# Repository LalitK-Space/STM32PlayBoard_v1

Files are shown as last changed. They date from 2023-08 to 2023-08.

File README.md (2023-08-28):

# STM32PlayBoard_v1

## Project Overview
<p>An STM32-based development board for boundless exploration in Embedded Systems. </p> 
Introducing the STM32PlayBoard. As the name suggests, the main object of developing this board is to expand my knowledge and provide an entry gate for others to learn Embedded Systems with a well-known and documented microcontroller by STMicroelectronics. 
<p>This project opens the door to immersive learning experiences and practical experimentation.

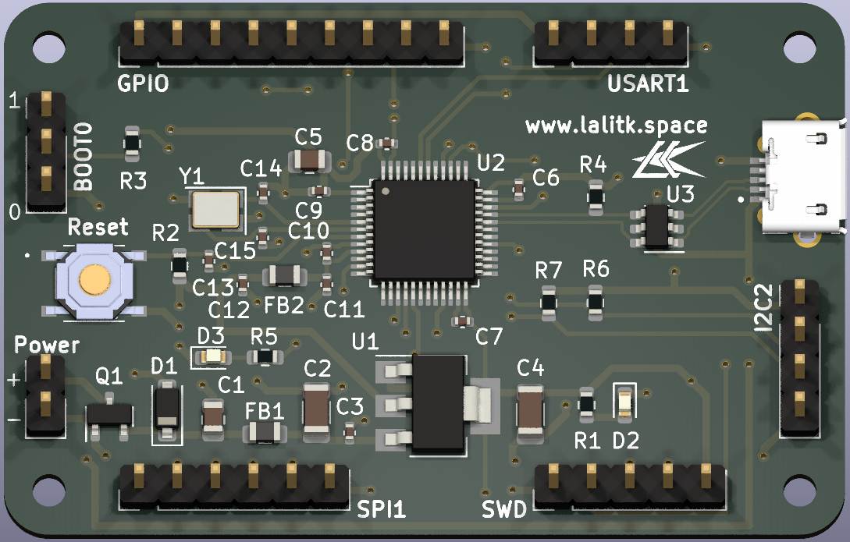
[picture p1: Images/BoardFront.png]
Top
 
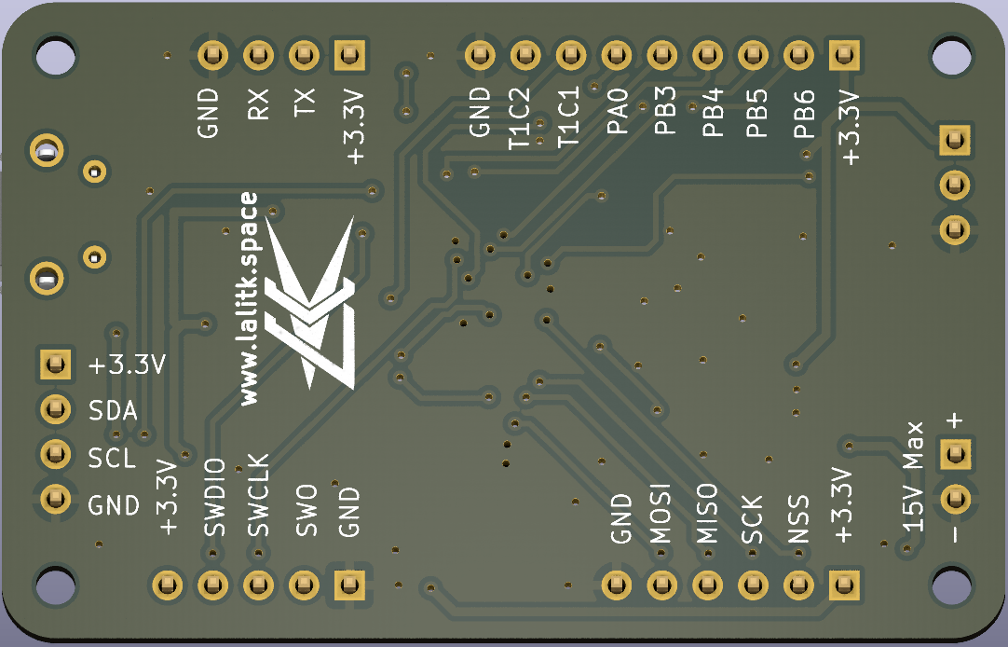
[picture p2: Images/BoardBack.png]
Bottom


## Why I Designed the STM32PlayBoard?
A Catalyst for Growth and Innovation, the reason for the development of STM32PlayBoard was rooted in a dual ambition: to push the boundaries of my expertise in PCB design while creating a versatile tool that resonates with my journey in Embedded Systems.
1.	**Elevating PCB Design Expertise:** This project moved me into a relatively complex PCB design I was familiar with. It also provided a stage to experiment with diverse PCB manufacturing and assembly services, broadening my understanding of the complexities of hardware production.
2.	**Fulfilling a Learning Trip:** While learning about ARM Cortex-M architectures, I have always used a variety of STMicroelectronics boards. Recently, I wanted to develop a basic yet peripheral-rich custom board.

## Design Philosophy
<p>I pictured a compact design for the STM32PlayBoard that prioritized accessibility to a wide range of communication protocols while offering dedicated pins for ADC, timers, and some general-purpose I/Os. 
<p>This careful pin allocation aimed to balance versatility, functionality, and ease in PCB designing. By providing exposure to commonly used communication interfaces and essential GPIO options, the board becomes an adaptable platform for various applications.
<p>Additionally, the compact nature of the design wasn't just about efficient use of space; it also served a practical purpose. I aimed to create a development board that could seamlessly integrate into my other projects as a convenient replacement. This design approach allows for easy adaptability across different projects, simplifying development and minimizing the need for significant redesigns.

## System Architecture
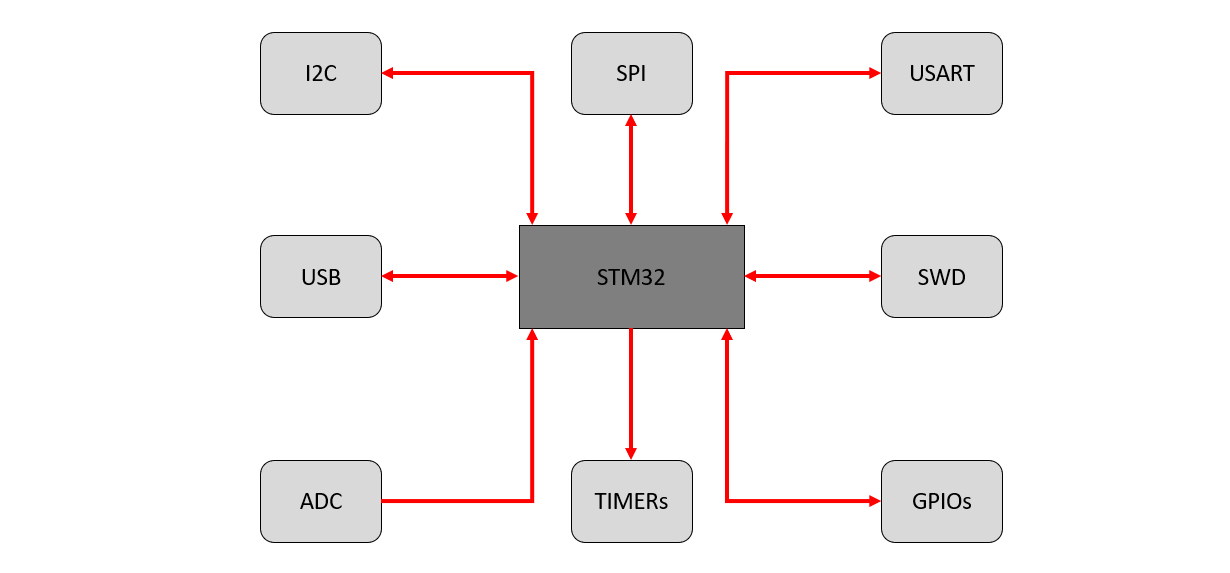
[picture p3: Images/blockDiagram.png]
Block Diagram/Architecture


## Board Component Selection
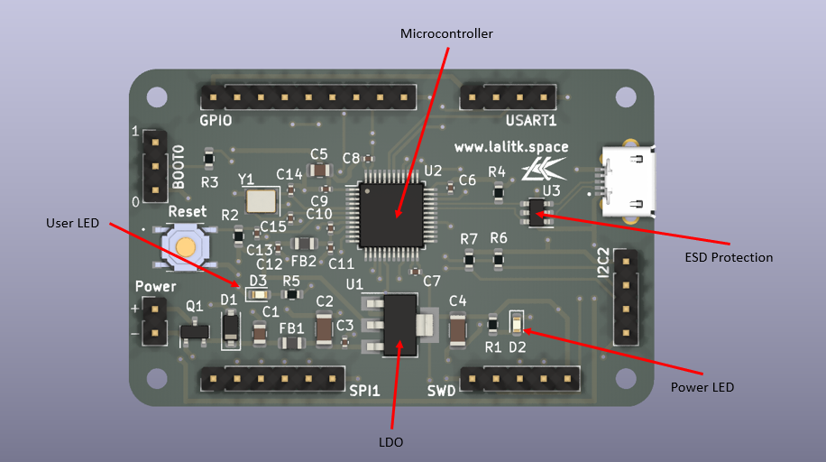
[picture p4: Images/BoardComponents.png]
Board Components

### Microcontroller:
1.	The board's core is an STM32F103C8T6 microcontroller from STMicroelectronics, running with a 16MHz High-Speed External Oscillator.
2.	Board has a configurable BOOT0 for different operational modes.
3.	A physical reset button for manually resetting the board.
### Power Supply:
1.	The board can be powered by an external voltage supply and through Micro B USB. They are reverse polarity protected and can both coexist.
2.	The voltage regulation is accomplished using AMS1117-3.3 linear voltage regulator from Advanced Monolithic Systems. Since the main component on the board is the main microcontroller IC, I went with this standard, less expensive, and easily available LDO.
3.	The maximum voltage that can be provided externally is 18V, and the maximum drop-out voltage of this LDO is 1.2V at 1A. We are going to be far from this current consumption using this board.
4. The Silkscreen on the back side of the PCB shows 15V is just an additional safety measure (not to exceed 15V even though up to 18V is acceptable).
### USB:
1.	The board supports USB 2.0 full-speed interface using a Micro B connector.
2.	The board provides ESD protection on USB using USBLC6 IC from STMicroelectronics.
### Onboard LEDs:
1.	D3 is onboard status LED and is connected to pin PA1. The cathode of the LED is permanent ground.
2.	D2 is the Power LED indicating a healthy power supply.

## PCB Design and Schematics:
### Schematics
[Schematics](https://github.com/LalitK-Space/STM32PlayBoard_v1/blob/main/STM32PlayBoard_Schematics/STM32PlayBoard_v1.pdf)

### Board Layout Considerations
1.	The PCB is two layered board. The reason for being two layers is I wanted to go with a simple board design, which also minimizes the production cost.
2.	The entire bottom layer of the board is grounded, and the Top layer is the signals layer.
3.	A wide trace of 0.5mm is for power, and a 0.3mm trace is for signals.
4. The board dimensions are 56x36mm. 
#### Front Copper
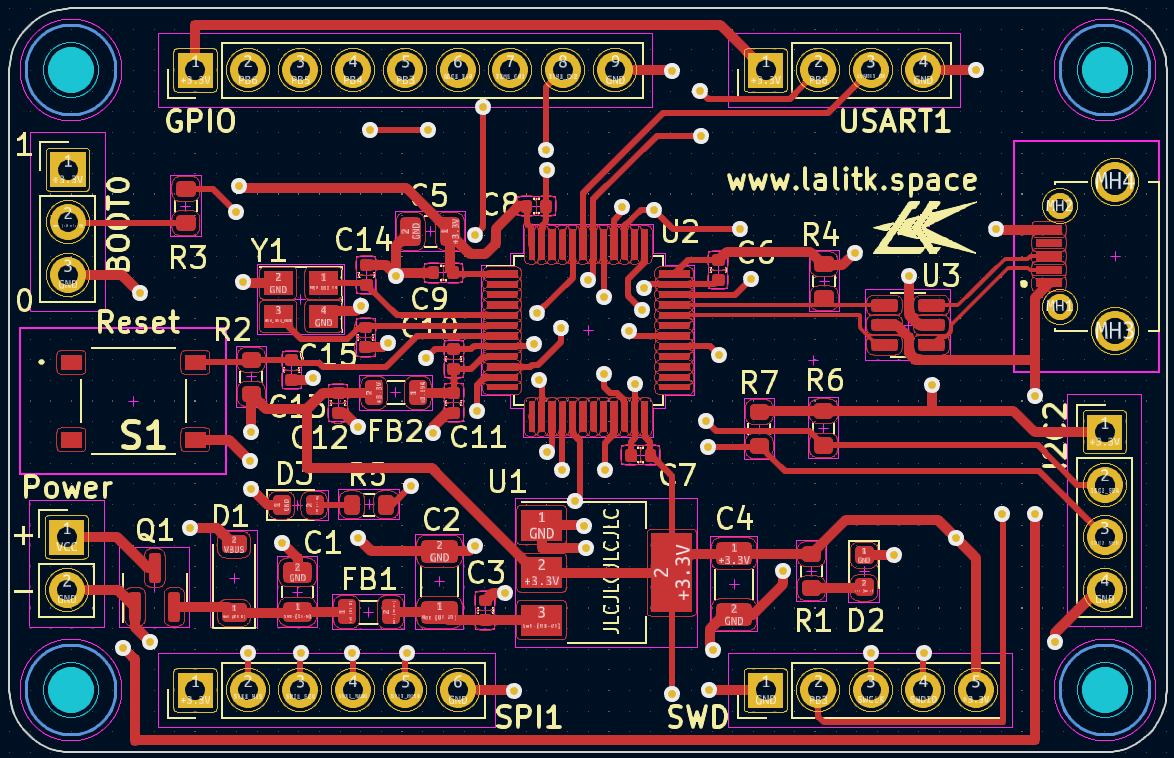
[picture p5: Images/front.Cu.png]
Front Copper

#### Back Copper
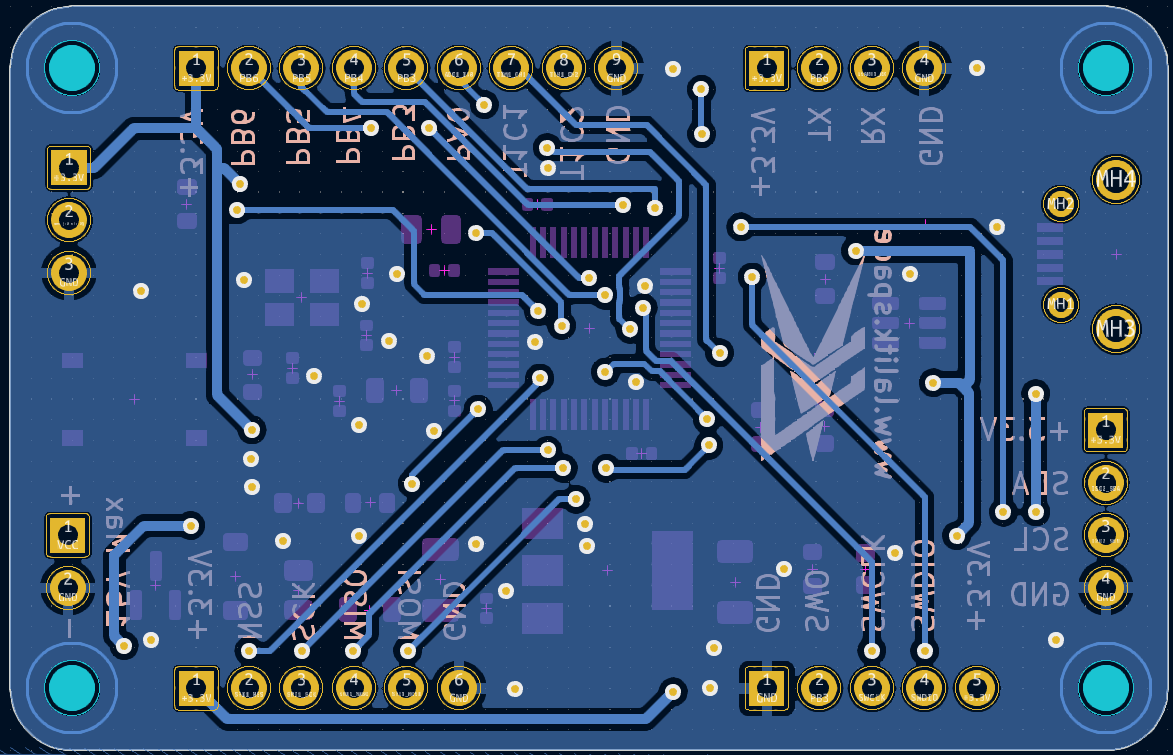
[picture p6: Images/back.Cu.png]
Back Copper


## Interfacing and Capabilities
1.	This board functions as a development board with GPIO and communication protocols exposed. 
The board exposes:
    <ul>
        <li>1 SPI connection (SPI1)</li>
        <li>1 I2C connection (I2C2)</li>
        <li>1 USART connection (USART1)</li>
        <li>SWD for programming and debugging</li>
        <li>1 ADC (ADC1_IN0)</li>
        <li>2 timers (TIM1_CH1 and TIM1_CH2)</li>
        <li>4 GPIOs from Port B (PB3, PB4, PB5, PB6)</li>
        <li>An onboard LED on pin PA1</li>
    </ul>
2. The voltage level for all the pins is 3.3V. And for interfacing with other 5V level compatible boards (for example, Arduino), a logic level shifter/converter is required.

## Software Development
The board can be programmed using an external ST-Link programmer via the SWD interface.

## Technical Specification
| Input Voltages | Max Values |
|---|:---:|
| Through USB connector | 5V | 
| Through Power connector | 18V |

| GPIO Tolerances | Max Values |
|---|:---:|
| All pins | 3.3V | 

| Memories | Size |
|---|:---:|
| FLASH | 64 Kbytes | 
| SRAM | 20 Kbytes | 

| Exposed Peripherals | Connected to |
|---|:---:|
| I2C2_SDA | PB11 | 
| I2C2_SCL | PB10 | 
| USART1_RX | PB7 |
| USART1_TX | PB6 |
| SPI1_NSS | PA4 |
| SPI1_SCK | PA5 |
| SPI1_MISO | PA6 |
| SPI1_MOSI | PA7 |
| Status LED D3 | PA1 |
| ADC1_IN0 | PA0 |
| TIM1_CH1 | PA8 |
| TIM1_CH2 | PA9 |
| GPIO1 (*USART1_TX*) | PB6 |
| GPIO2 | PB5 |
| GPIO3 | PB4 |
| GPIO4 (*SWO*) | PB3 |

## Board Bring-Up
### Manufactured and Assembled Board
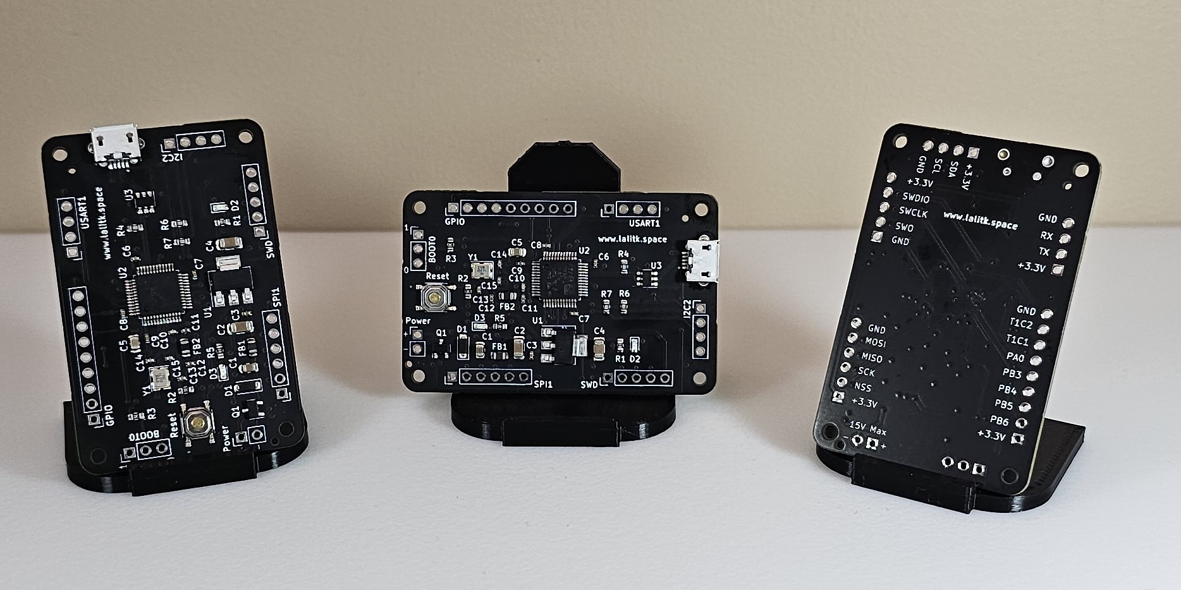
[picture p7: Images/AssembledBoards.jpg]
Assembled Boards

### Powering Up and Blinking Onboard LED
It's Alive

## My learnings
<p>Throughout the development of this board, I discovered a lot regarding designing a PCB with a microcontroller on it and various design practices like decoupling and bulk capacitors. I also wanted to learn to program a STMicroelectronics microcontroller using an external programmer, and I achieved this using this board.
<p>As per software development skills, I am writing my drivers for various peripherals and example codes for this board, which are available on this GitHub repository. 

## Foundations for the Future
<p>Keeping this project as a base, I would like to design and develop another STM32-based development board with a different, more powerful microcontroller with various onboard peripherals like FLASH memory and some onboard sensors communicating with the main IC using multiple communication protocols.

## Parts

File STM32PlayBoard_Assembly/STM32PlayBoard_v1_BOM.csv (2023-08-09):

Comment | Designator | Footprint | LCSC
10u | C1, C5 | Capacitor_SMD:C_0805_2012Metric | C15850
22u | C2, C4 | Capacitor_SMD:C_1206_3216Metric | C12891
100n | C3, C6, C7, C8, C9, C13 | Capacitor_SMD:C_0402_1005Metric | C1525
10n | C10 | Capacitor_SMD:C_0402_1005Metric | C15195
1u | C11, C12 | Capacitor_SMD:C_0402_1005Metric | C52923
10p | C14, C15 | Capacitor_SMD:C_0402_1005Metric | C32949
1N5819WS | D1 | Diode_SMD:D_SOD-123 | C8598
Power_LED | D2 | LED_SMD:LED_0603_1608Metric | C2286
Status_LED | D3 | LED_SMD:LED_0603_1608Metric | C2286
600Î©@100MHz | FB1, FB2 | Inductor_SMD:L_0805_2012Metric | C1017
MountingHole | H1, H2, H3, H4 | MountingHole:MountingHole_2.2mm_M2
PowerIN | J1 | Connector_PinHeader_2.54mm:PinHeader_1x02_P2.54mm_Vertical
BOOT0 | J2 | Connector_PinHeader_2.54mm:PinHeader_1x03_P2.54mm_Vertical
USB_B_Micro | J3 | Micro-B:MICROXNJ | C404969
I2C2 | J4 | Connector_PinHeader_2.54mm:PinHeader_1x04_P2.54mm_Vertical
USART1 | J5 | Connector_PinHeader_2.54mm:PinHeader_1x04_P2.54mm_Vertical
GPIO/Timer/ADC | J6 | Connector_PinHeader_2.54mm:PinHeader_1x09_P2.54mm_Vertical
SWD | J7 | Connector_PinHeader_2.54mm:PinHeader_1x05_P2.54mm_Vertical
SPI1 | J8 | Connector_PinHeader_2.54mm:PinHeader_1x06_P2.54mm_Vertical
AO3401A | Q1 | Package_TO_SOT_SMD:SOT-23 | C15127
1k | R1, R5 | Resistor_SMD:R_0603_1608Metric | C21190
10k | R2, R3 | Resistor_SMD:R_0603_1608Metric | C25804
1.5k | R4, R6, R7 | Resistor_SMD:R_0603_1608Metric | C22843
TS-1187A-B-A-B | S1 | KiCad:TS1187ABAB | C318884
AMS1117-3.3 | U1 | Package_TO_SOT_SMD:SOT-223-3_TabPin2 | C6186
STM32F103C8Tx | U2 | Package_QFP:LQFP-48_7x7mm_P0.5mm | C8734
USBLC6-2SC6 | U3 | Package_TO_SOT_SMD:SOT-23-6 | C7519
16MHz | Y1 | Crystal:Crystal_SMD_SeikoEpson_TSX3225-4Pin_3.2x2.5mm | C13738

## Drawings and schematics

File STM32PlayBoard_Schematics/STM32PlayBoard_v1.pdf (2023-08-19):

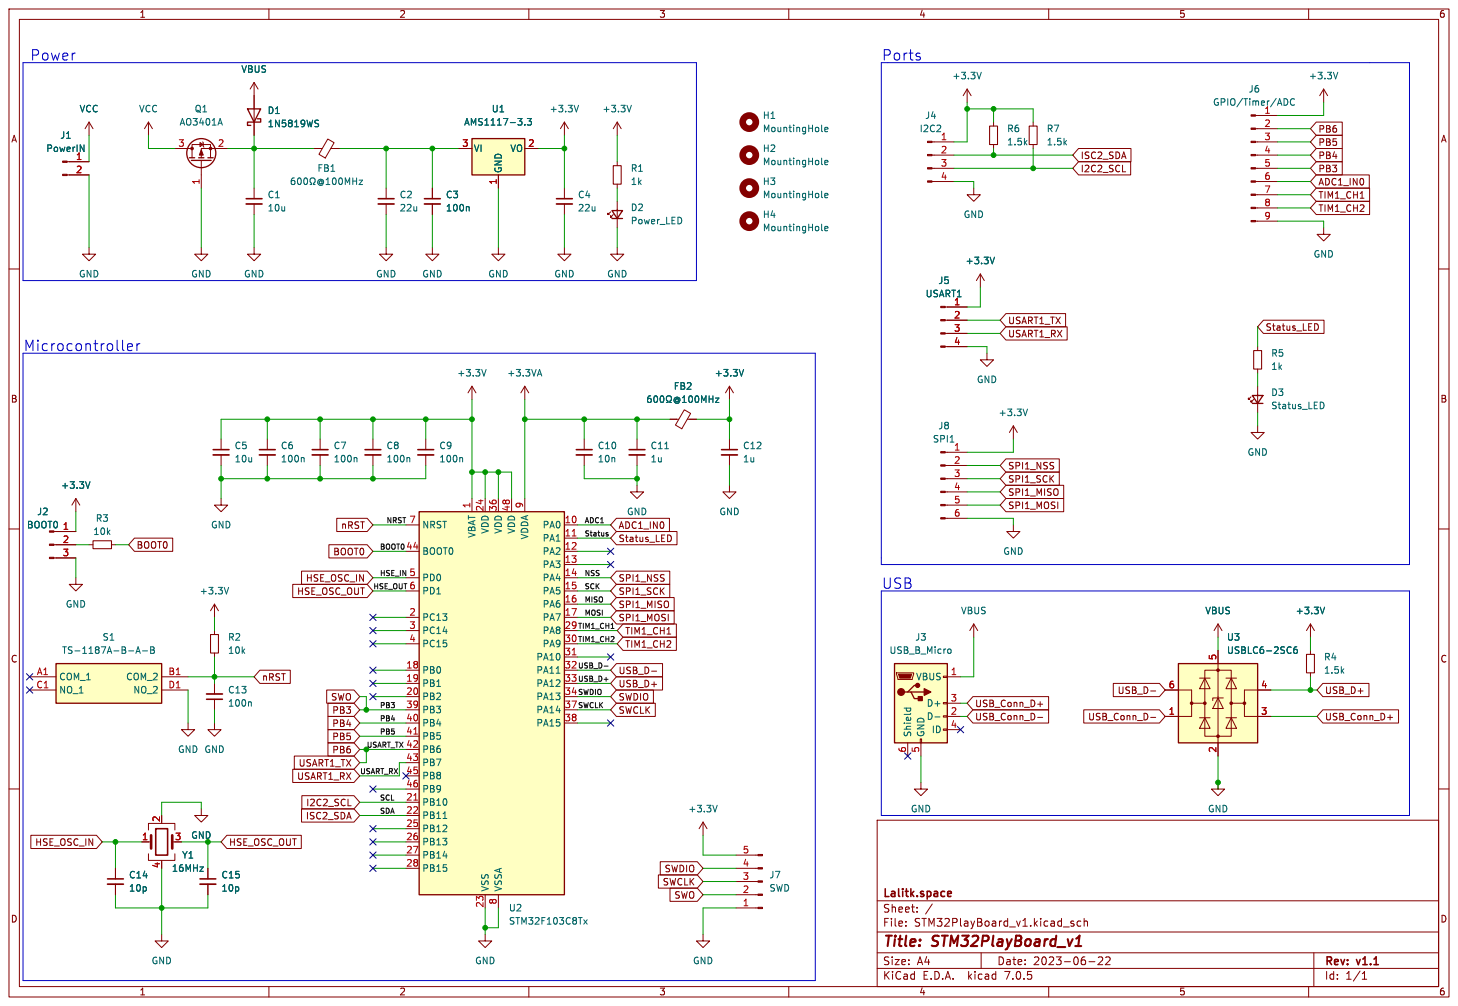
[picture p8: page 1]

1 PA0 10 PA1 11 PA2 12 PA3 13 PA4 14 PA5 15 PA6 16 PA7 17 PB0 18 PB1 19 PC13 2 PB2 20 PB10 21 PB11 22 VSS 23 VDD 24 PB12 25 PB13 26 PB14 27 PB15 28 PA8 29 PC14 3 PA9 30 PA10 31 PA11 32 PA12 33 PA13 34 VDD 36 PA14 37 PA15 38 PB3 39 PC15 4 PB4 40 PB5 41 PB6 42 PB7 43 BOOT0 44 PB8 45 PB9 46 VDD 48 PD0 5 PD1 6 NRST 7 VSSA

File: STM32PlayBoard_v1.kicad_sch Sheet: / Lalitk.space

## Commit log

2023-08-09 Create STM32PlayBoard_v1.pdf
    Board Schematics (.pdf)
2023-08-09 Gerber Files
    Gerber files for PCB manufacturing
    [STM32PlayBoard_v1-B_Cu.gbr, STM32PlayBoard_v1-B_Mask.gbr, STM32PlayBoard_v1-B_Paste.gbr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]
2023-08-09 Assembly Files
    Bill of Materials and Footprint Position File for PCB assembly
    [STM32PlayBoard_v1_BOM.xlsx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]
2023-08-09 Bill of Materials in .csv format
    Replaced BOM with .csv format
    [STM32PlayBoard_v1_BOM.csv, STM32PlayBoard_v1_BOM.xlsx]
2023-08-09 Update STM32PlayBoard_v1.pdf
    Updated Schematics
2023-08-11 Updated Board Information
2023-08-11 Added Board Images
2023-08-12 Board Bring Up
2023-08-16 Create stm32f103xx.h
    STM32F103xx specific details
2023-08-17 NVIC Register Addresses
    Nested Vectored Interrupt Controller Peripheral register addresses defined (MACROS)
2023-08-18 Update STM32PlayBoard_v1.pdf
    Corrected connection error (SWO pin -> PB3)
2023-08-19 Updated Images
    After schematic correction
2023-08-19 Updated Manufacturing Files
    Updated after schematic correction
    [STM32PlayBoard_v1-B_Cu.gbr, STM32PlayBoard_v1-B_Mask.gbr, STM32PlayBoard_v1-B_Paste.gbr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]
2023-08-19 Updated Assembly Files
    After schematics update
    [STM32PlayBoard_v1-B_Cu.gbr, STM32PlayBoard_v1-B_Mask.gbr, STM32PlayBoard_v1-B_Paste.gbr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]
2023-08-28 Update stm32f103xx.h
    Started Adding Base Addresses of Peripherals.
